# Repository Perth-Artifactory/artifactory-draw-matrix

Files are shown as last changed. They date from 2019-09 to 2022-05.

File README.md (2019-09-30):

# Artifactory Draw Matrix
A WiFi controlled LED matrix that acts as a drawing canvas.

<!--![Artifactory Draw](photos/IMG_20190930_155304.jpg =750x)-->

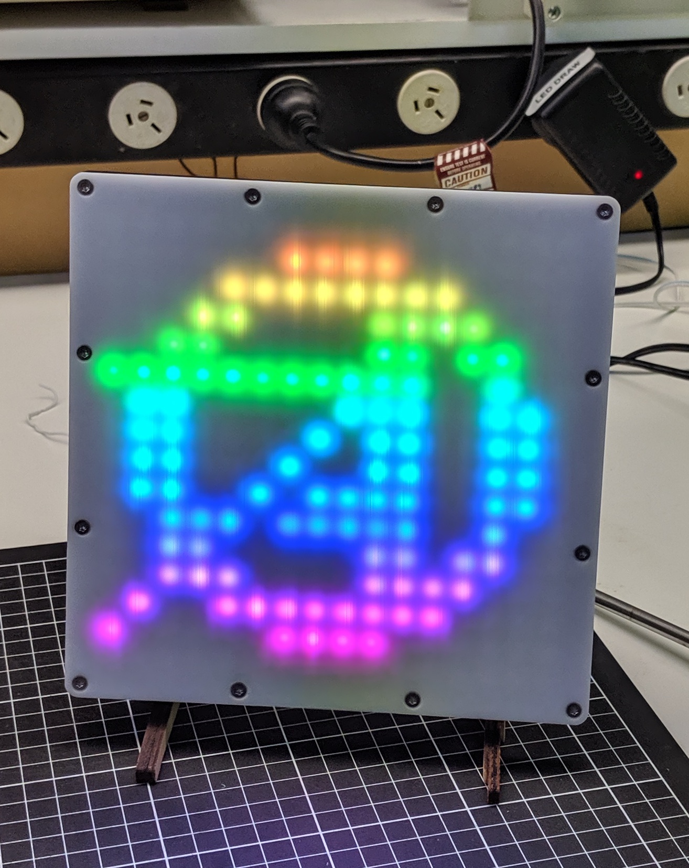
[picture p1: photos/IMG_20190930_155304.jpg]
Photo of Artifactory Draw


`artifactory-draw-matrix.ino` is the code for Arduino IDE for running on a Wemos D1 mini variant of a ESP8266. The LED matrx is a WS2812B type. At max brightness white colour you could expect 4A at 5V draw. 

The purpose of the circuit is to level shift the 3.3V output of ESP8266 up to a level reliably compatible with the LEDs which expect 5V logic. Although various 5V LED strips and matrices do somtimes work with 3.3V microcontrollers it is not reliable. If you see flickering of the LEDs during animations while driving a 5V LED strip/matrix directly from a 3.3V micro then lack of level shifting may be the problem. Typical SPI/I2C level shifters don't seem to work. From various recommendations the 74HC245 buffer was used. Its a big chip at 20 pins but works well.

The rest of the circuit is general recommendations for LED strips: 200 to 500 ohm resistor in series with data pin and 1000uF cap across power supply near LED strip. See https://learn.adafruit.com/adafruit-neopixel-uberguide/best-practices.

The inspiration and much of the code is from Rui (Ray) Wang's WiFi-enabled LEDWorkshop: https://rayshobby.net/wordpress/wifi-color-led-matrix/. So thanks to him for that.

The CAD files to build the LED matrix enclosure are also included here and consist of DXF files for laser cut acrylic. White is best for front since it will help diffuse the very bright LEDs.

When the microcontroller is on, it will present a wifi access point for you to connect to. On connection, a captive portal will prompt your phone or laptop to open http://1.3.3.7/ (the ESP's IP address). At this address will be a simple web interface for drawing along with some included patterns.

The code also has provision to operate in a mode where it connects to an existing wifi network. Set `apMode=false` and enter wifi details.

Pressing the button on back of unit will disable responding to wifi and play a rainbow animation of Artifactory logo. Pressing the button again or restarting the unit will switch it back to wifi mode. This is to make it easy stop it showing unwanted/offensive things.

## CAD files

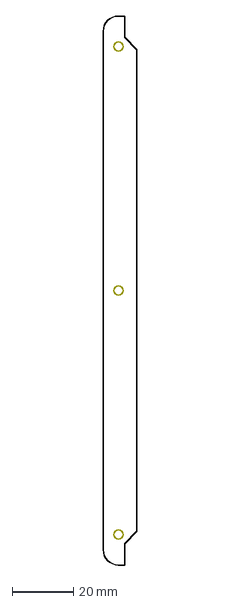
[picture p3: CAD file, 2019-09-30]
cad_files/16x16/back cutout05.dxf
11.0 x 180.0 mm

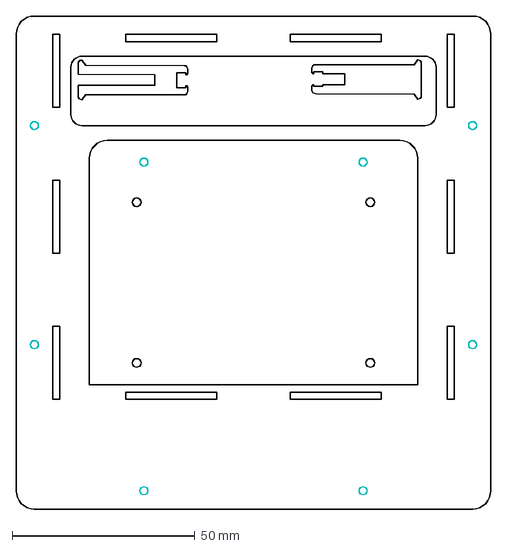
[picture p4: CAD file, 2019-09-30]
cad_files/16x16/back/#board cover 3mm.dxf
130.0 x 135.0 mm

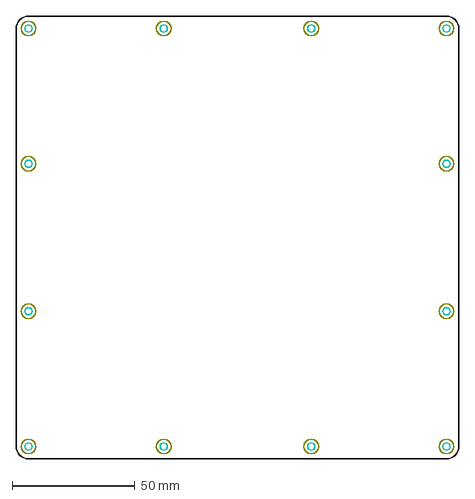
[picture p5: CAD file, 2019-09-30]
cad_files/16x16/complete/front.dxf
180.0 x 180.0 mm

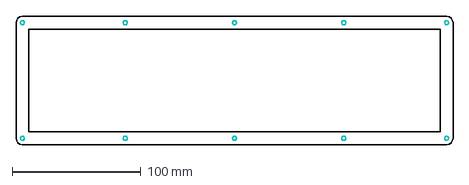
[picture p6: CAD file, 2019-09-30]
cad_files/32x8/Complete/middle.dxf
340.0 x 100.0 mm

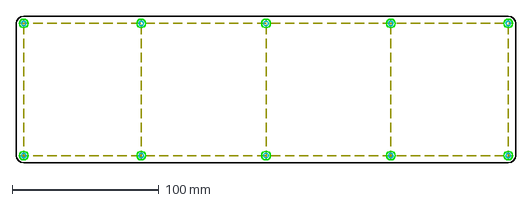
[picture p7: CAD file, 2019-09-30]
cad_files/32x8/front.dxf
340.0 x 100.0 mm

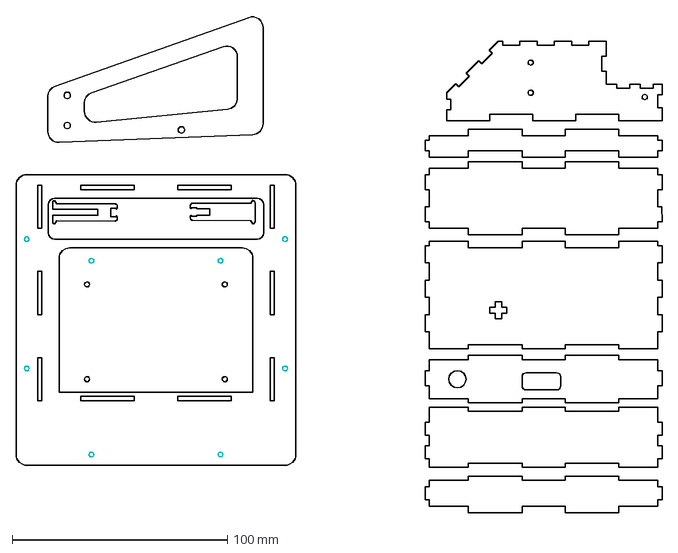
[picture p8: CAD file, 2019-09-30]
cad_files/16x16/back/board cover.dxf
300.0 x 230.5 mm

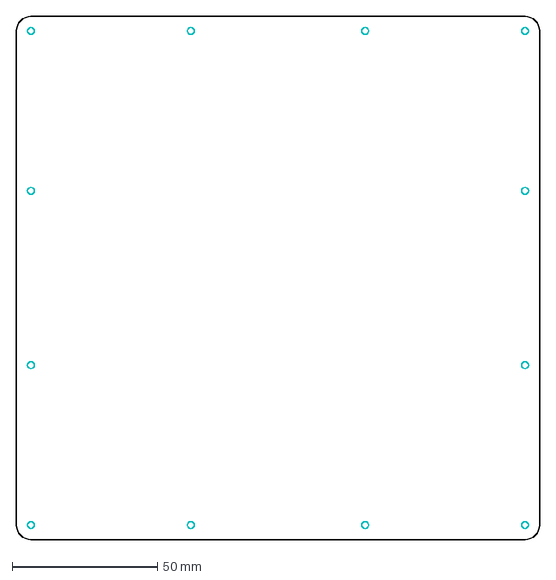
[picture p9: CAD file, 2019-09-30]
cad_files/16x16/complete/Back.dxf
180.0 x 180.0 mm

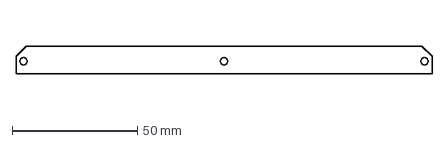
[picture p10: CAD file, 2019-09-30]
cad_files/16x16/side04.dxf
166.0 x 11.0 mm

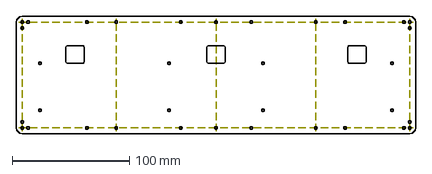
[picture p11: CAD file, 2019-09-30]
cad_files/32x8/cable back.dxf
340.0 x 100.0 mm

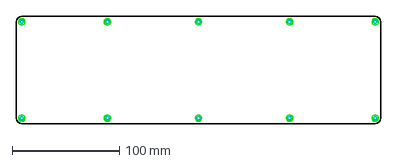
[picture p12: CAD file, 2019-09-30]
cad_files/32x8/Complete/Front.dxf
340.0 x 100.0 mm

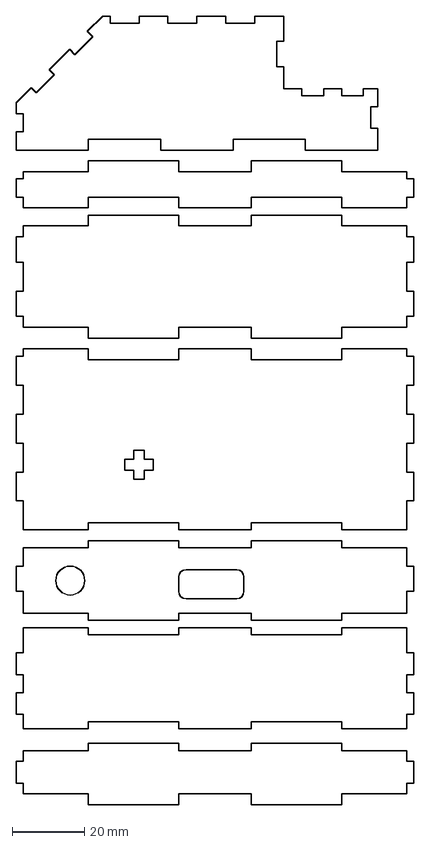
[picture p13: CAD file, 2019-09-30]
cad_files/16x16/back/#board cover 2mm.dxf
110.0 x 218.0 mm

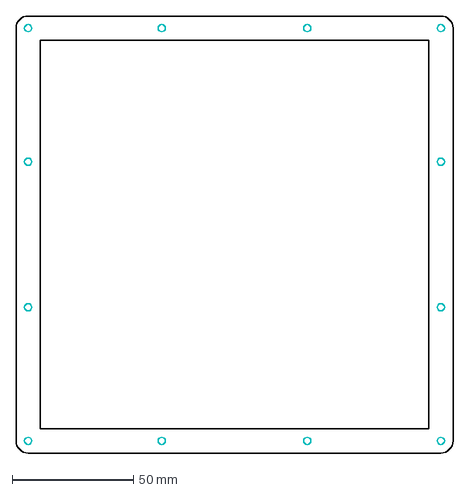
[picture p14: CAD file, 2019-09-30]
cad_files/16x16/complete/middle.dxf
180.0 x 180.0 mm

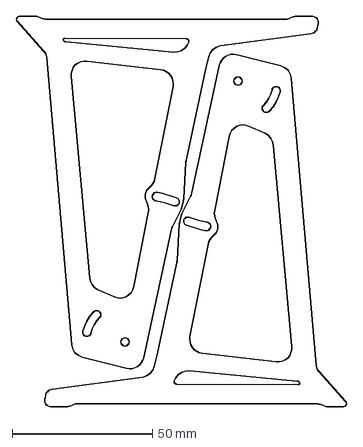
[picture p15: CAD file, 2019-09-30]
cad_files/16x16/legs3.dxf
117.8 x 139.0 mm

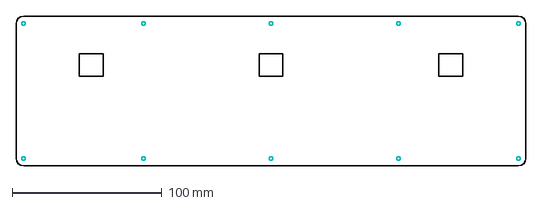
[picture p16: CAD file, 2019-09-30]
cad_files/32x8/Complete/cable back.dxf
340.0 x 100.0 mm

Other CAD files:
cad_files/32x8/middle.dxf
cad_files/16x16/complete/back cutout.dxf
cad_files/16x16/side05.dxf
cad_files/32x8/Back.dxf
cad_files/16x16/Front.dxf
cad_files/16x16/back cutout.dxf
cad_files/16x16/back cutout02.dxf
cad_files/16x16/back cutout03.dxf
cad_files/16x16/back.dxf
cad_files/16x16/back/board cover 2mm.dxf
cad_files/16x16/back/board cover 3mm.dxf
cad_files/32x8/Complete/back.dxf

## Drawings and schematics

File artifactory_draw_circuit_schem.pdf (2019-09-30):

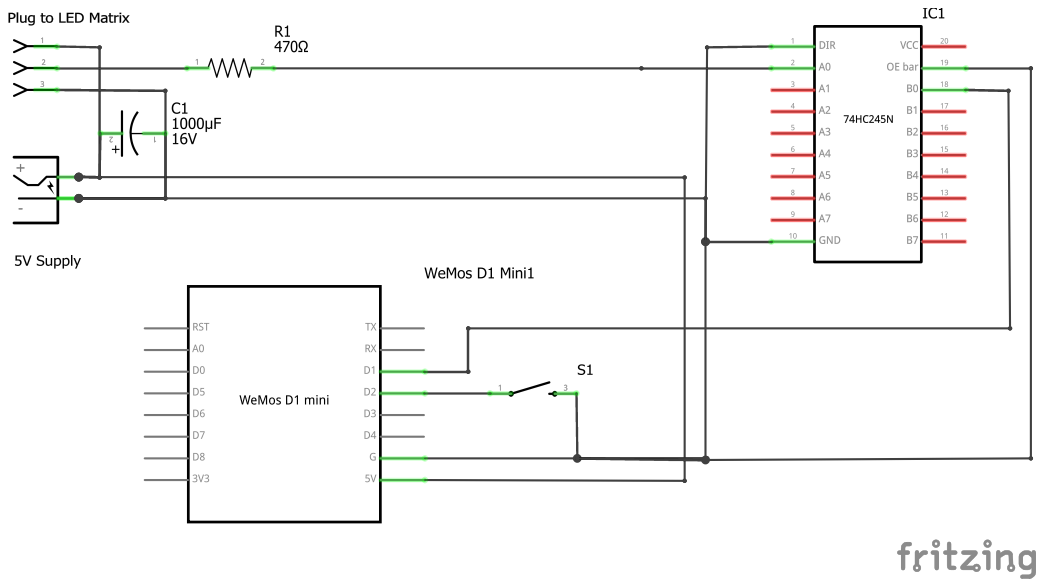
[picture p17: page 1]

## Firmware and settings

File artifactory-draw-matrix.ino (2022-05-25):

////////////////////////////////////////////////////////////////////////////////////
/// Artifactory Wifi LED Drawing
///
/// Based on code from Rui (Ray) Wang's WiFi-enabled LEDWorkshop
/// https://rayshobby.net/wordpress/wifi-color-led-matrix/
///

#include <ESP8266WiFi.h>
#include <DNSServer.h>
#include <ESP8266WebServer.h>
#include <Adafruit_NeoPixel.h>
#include "pixart.h"

#define PIN_BUTTON  D2
#define PIN_LED     D1
#define NUM_LEDS    256
#define ROWS        16
#define COLS        16

#define MODE_COUNT   2
#define MODE_DRAW    0
#define MODE_OFFLINE 1



// https://intrinsically-sublime.github.io/FastLED-XY-Map-Generator/
// XY mapping function preserving all pixel data.
// Requires 771 Bytes's of SRAM and 7.71 ms/frame for WS2811 based LEDs.
// You COULD save 0 Bytes's of SRAM and 0.00 ms/frame for WS2811 based LEDs.
// Maximum frame rate for WS2811 based LEDs = 129 FPS using 1 output.
// Wired in horizontal serpentine layout starting at the top left corner.

// Parameters for width and height
#define MATRIX_WIDTH 16
#define MATRIX_HEIGHT 16

uint16_t XY (uint8_t x, uint8_t y) {
  // map anything outside of the matrix to the extra hidden pixel
  if (x >= MATRIX_WIDTH || y >= MATRIX_HEIGHT) { return 256; }

  const uint16_t XYTable[] = {
       0,  31,  32,  63,  64,  95,  96, 127, 128, 159, 160, 191, 192, 223, 224, 255,
       1,  30,  33,  62,  65,  94,  97, 126, 129, 158, 161, 190, 193, 222, 225, 254,
       2,  29,  34,  61,  66,  93,  98, 125, 130, 157, 162, 189, 194, 221, 226, 253,
       3,  28,  35,  60,  67,  92,  99, 124, 131, 156, 163, 188, 195, 220, 227, 252,
       4,  27,  36,  59,  68,  91, 100, 123, 132, 155, 164, 187, 196, 219, 228, 251,
       5,  26,  37,  58,  69,  90, 101, 122, 133, 154, 165, 186, 197, 218, 229, 250,
       6,  25,  38,  57,  70,  89, 102, 121, 134, 153, 166, 185, 198, 217, 230, 249,
       7,  24,  39,  56,  71,  88, 103, 120, 135, 152, 167, 184, 199, 216, 231, 248,
       8,  23,  40,  55,  72,  87, 104, 119, 136, 151, 168, 183, 200, 215, 232, 247,
       9,  22,  41,  54,  73,  86, 105, 118, 137, 150, 169, 182, 201, 214, 233, 246,
      10,  21,  42,  53,  74,  85, 106, 117, 138, 149, 170, 181, 202, 213, 234, 245,
      11,  20,  43,  52,  75,  84, 107, 116, 139, 148, 171, 180, 203, 212, 235, 244,
      12,  19,  44,  51,  76,  83, 108, 115, 140, 147, 172, 179, 204, 211, 236, 243,
      13,  18,  45,  50,  77,  82, 109, 114, 141, 146, 173, 178, 205, 210, 237, 242,
      14,  17,  46,  49,  78,  81, 110, 113, 142, 145, 174, 177, 206, 209, 238, 241,
      15,  16,  47,  48,  79,  80, 111, 112, 143, 144, 175, 176, 207, 208, 239, 240
  };

  return XYTable[(y * MATRIX_WIDTH) + x];
}



// Neopixel object
Adafruit_NeoPixel leds = Adafruit_NeoPixel(NUM_LEDS, PIN_LED, NEO_GRB + NEO_KHZ800);

int mode_index = 0;

byte brightness = 48;       // was: 80, default brightness: 48
uint32_t pixels[NUM_LEDS];  // pixel buffer. this buffer allows you to set arbitrary
// brightness without destroying the original color values

unsigned long button_last = 0;
bool initial_demo = true;
bool enableLEDs = false;

// Wifi Setup
// Based on stuff from https://www.hackster.io/rayburne/esp8266-captive-portal-5798ff
const bool apMode = false;
const char *      ap_name = "ArtifactoryDraw";
const byte        DNS_PORT = 53;          // Capture DNS requests on port 53
IPAddress         apIP(1, 3, 3, 7);    // Private network for server
DNSServer         dnsServer;              // Create the DNS object
ESP8266WebServer  server(80);          // HTTP server

// Wifi setup for connecting to an access point
char* ssid = "";
char* password = "";
bool staticIP = false;
IPAddress ip(10, 42, 0, 200); // where xx is the desired IP Address
IPAddress gateway(10, 42, 0, 1); // set gateway to match your network
IPAddress subnet(255, 255, 255, 0); // set subnet mask to match your



// Forward declare functions
void ICACHE_RAM_ATTR button_handler();
//void button_handler();  // causes error with NodeMCU board firmware ver: 2.5.2
void on_status();
void on_change_color();
void on_homepage();
void show_leds();



void show_leds() {
  uint32_t r, g, b;
  uint32_t c;
  for (int i = 0; i < NUM_LEDS; i++) {
    r = (pixels[i] >> 16) & 0xFF;
    g = (pixels[i] >> 8) & 0xFF;
    b = (pixels[i]) & 0xFF;
    r = r * brightness / 255;
    g = g * brightness / 255;
    b = b * brightness / 255;
    c = (r << 16) + (g << 8) + b;
    leds.setPixelColor(i, c);
  }
  if (enableLEDs) {
    leds.show();
  }
  else
  {
    delay(100);
  }
}

void setup() {
  Serial.begin(115200);
  Serial.println();
  Serial.println("Led Drawing 16x16");

  // Set pin mode
  pinMode(PIN_BUTTON, INPUT_PULLUP);
  pinMode(PIN_LED,    OUTPUT);

  // If button is pressed when starting. Dont show LEDs.
  // Useful for flashing by USB where you dont want to connect 5V
  enableLEDs = digitalRead(PIN_BUTTON); // PULLUP: Normally High

  if (enableLEDs) {
    Serial.println("LED output is enabled");
  } else {
    Serial.println("Button pressed! LED output is disabled");
  }

  // Delay for recovery
  delay(3000);
  
  Serial.println("Ready!");

  // Initialize LEDs
  leds.begin();
  leds.show();

  // Set WiFi
  if (apMode) {
    WiFi.mode(WIFI_AP);
    WiFi.softAPConfig(apIP, apIP, IPAddress(255, 255, 255, 0));
    WiFi.softAP(ap_name);
  
    // if DNSServer is started with "*" for domain name, it will reply with
    // provided IP to all DNS request
    dnsServer.start(DNS_PORT, "*", apIP);
  } else {
    if (staticIP) {
      Serial.print(F("Setting static ip to: "));
      Serial.println(ip);
      WiFi.config(ip, gateway, subnet);
    }
    
    WiFi.mode(WIFI_STA);
    Serial.printf("Connecting to %s\n", ssid);
    if (String(WiFi.SSID()) != String(ssid)) {
      WiFi.begin(ssid, password);
    }

    while (WiFi.status() != WL_CONNECTED) {
      delay(500);
      Serial.print(".");
    }

    Serial.print("Connected! Open http://");
    Serial.print(WiFi.localIP());
    Serial.println(" in your browser");
  }
  
  server.enableCORS(true);

  // Set server callback functions
  server.onNotFound(on_homepage);
  server.on("/",   on_homepage);
  server.on("/js", on_status);
  server.on("/cc", on_change_color);
  server.begin();

  // Set button handler
  attachInterrupt(PIN_BUTTON, button_handler, FALLING);

}

// The variable below is modified by interrupt service routine
// so declare it as volatile
volatile boolean button_clicked = false;

void loop() {
  if (apMode) {
    dnsServer.processNextRequest();
  }
  
  server.handleClient();

  // if (initial_demo) {
  //   display_artifactory_logo();
  //   initial_demo = false;
  // }

  if (initial_demo || mode_index == MODE_OFFLINE) {
    static int delayer = 100;
    delayer -= 1;
    if (delayer == 0) {
      display_artifactory_logo();
      delayer = 100;
    }
    delayMicroseconds(100); // was: 100
  }

  if (button_clicked) {
    if (millis() - button_last > 1000) {
      mode_index += 1;
      mode_index %= MODE_COUNT;
      Serial.print("Mode changed to ");
      Serial.println(mode_index);
      button_last = millis();
    }
    button_clicked = false;
  }
}









// Take an index for a normal c++ array layout and 
// flip it to match led connection order
// (from Artifactory LED Matrx)
int remap_led_index(int pos) {
  int x = pos % MATRIX_WIDTH;
  int y = pos / MATRIX_WIDTH;
  int index = XY(x, y);
  return index;
}

/// Remap pixart to match led connection order using a lookup table
void hexcolour_snake(const uint32_t *arr) {
  for (uint16_t t = 0; t < NUM_LEDS; t++) {
    int new_index = remap_led_index(t);
    pixels[new_index] = arr[t];
  }
  show_leds();
}

void hexcolour_snake_wheel(const uint32_t *arr, byte initial) {
  for (uint16_t t = 0; t < NUM_LEDS; t++) {
    int new_index = remap_led_index(t);
    //pixels[new_index] = wheel((initial + t/16) & 0xFF) * ((arr[t] & 0xFF) / 255.0);
    pixels[new_index] = wheel_bright((initial + t) & 0xFF, ((arr[t] & 0xFF) / 255.0));
    //pixels[new_index] = wheel((initial + t) & 0xFF);
  }
  show_leds();
}


uint32_t wheel(int WheelPos) {
  WheelPos = 255 - WheelPos;
  if (WheelPos < 85) {
    return leds.Color(255 - WheelPos * 3, 0, WheelPos * 3);
  }
  if (WheelPos < 170) {
    WheelPos -= 85;
    return leds.Color(0, WheelPos * 3, 255 - WheelPos * 3);
  }
  WheelPos -= 170;
  return leds.Color(WheelPos * 3, 255 - WheelPos * 3, 0);
}

uint32_t wheel_bright(int WheelPos, double b) {
  WheelPos = 255 - WheelPos;
  if (WheelPos < 85) {
    return leds.Color(b * (255 - WheelPos * 3), 0, b * (WheelPos * 3));
  }
  if (WheelPos < 170) {
    WheelPos -= 85;
    return leds.Color(0, b * (WheelPos * 3), b * (255 - WheelPos * 3));
  }
  WheelPos -= 170;
  return leds.Color(b * (WheelPos * 3), b * (255 - WheelPos * 3), 0);
}

void display_artifactory_logo() {
  static byte idx = 0;

  //hexcolour_snake(pixart_artifactory_logo);
  hexcolour_snake_wheel(pixart_artifactory_logo, idx);

  idx += 1;
  idx %= 256;

}

/* ----------------
    WebServer for Drawing
   ---------------- */

#include "html.h"
void on_homepage() {
  String html = FPSTR(index_html);
  if (mode_index == MODE_DRAW) {
    server.send(200, "text/html", html);
  } else if (mode_index == MODE_OFFLINE) {
    server.send(200, "text/html", "Artifactory Draw is Offline");
  }
}

// this returns device variables in JSON, e.g.
// {"pixels":xxxx,"blink":1}
void on_status() {
  String html = "";
  html += "{\"brightness\":";
  html += brightness;
  html += "}";
  server.send(200, "text/html", html);
}

void on_change_color() {

  uint16_t i;
  if (server.hasArg("pixels")) {
    String val = server.arg("pixels");
    for (i = 0; i < NUM_LEDS; i++) {
      // every pixel color is 6 bytes storing the hex value
      // pixels are specified in row-major order
      // here we need to flip it to column-major order to
      // match the physical connection of the leds

      /*int r = i / 16, c = i % 16;
      //pixels[c*16+r] = strtol(val.substring(i*6, i*6+6).c_str(), NULL, 16);
      int index = 0;
      if (r % 2 == 1) {
        index = c + r * 16;
      } else {
        index = (15 - c) + r * 16;
      }*/

      int index = remap_led_index(i);

      pixels[index] = strtol(val.substring(i * 6, i * 6 + 6).c_str(), NULL, 16);
    }
  }
  if (server.hasArg("clear")) {
    for (i = 0; i < NUM_LEDS; i++) {
      pixels[i] = 0;
    }
  }
  /*if(server.hasArg("brightness")) {
    brightness = server.arg("brightness").toInt();
    }*/

  initial_demo = false;
  show_leds();

  server.send(200, "text/html", "{\"result\":1}");
}

char dec2hex(byte dec) {
  if (dec < 10) return '0' + dec;
  else return 'A' + (dec - 10);
}

void button_handler() {
  button_clicked = true;
}

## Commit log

2019-09-30 Add schematic
    [artifactory_draw_circuit.fzz]
2019-09-30 Add Kamil's CAD files
    [#board cover 2mm.dxf, #board cover 3mm.dxf, Back.dxf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]
2021-06-15 Fix for button handler crash
    [artifactory-draw-matrix.ino]
2022-04-20 Add colour wheel to artifactory logo. Add to wifi.
